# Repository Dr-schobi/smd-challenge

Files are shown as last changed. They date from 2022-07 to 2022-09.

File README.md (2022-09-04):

# SMD soldering challenge

https://user-images.githubusercontent.com/78444256/188329124-fbfda367-b1dc-41d7-a8d5-ee6e349dee65.mp4

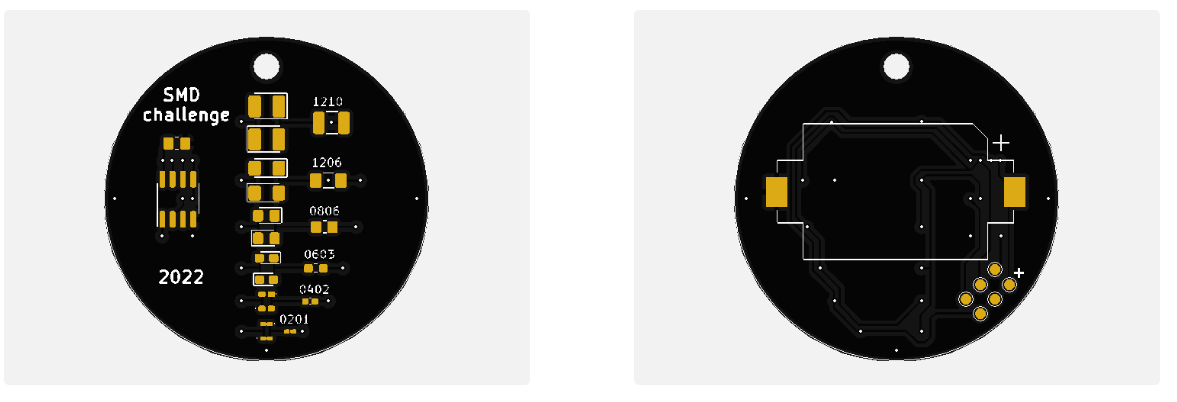
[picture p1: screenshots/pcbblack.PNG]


This project is about hand-soldering tiny SMD components onto a PCB. Similar to [Defcon](https://dchhv.org/events/smdsolderchallenge.html) in [2018](https://hackaday.com/2018/08/02/smd-soldering-challenge-lands-at-def-con/).

My goals:
- I wanna try! (both with and without extra tools).
  In the past, I've done some PCB development, debugging, soldering and measuring around 2008 for developing digital cameras, with large FPGAs (Xilinx Vertex), my own DDR memory controller on complex 10+ layer PCBs. Back then, this was no 0201 and I'm much older now with many years of just Matlab coding and only little electronics. 

- I don't think that I will succeed on the first try.
  I will need more than one shot with the tiny components, especially towards 0201. 
  the kit from the set above comes with one component each - this might not be enough.

- Learn some more! 
  The new Kicad 6 looks realy good and I'm lacking practice in PCB design, this looks like a good chance for a quick project with focus on aesthetics.   
  I've not worked wit Atmel microcontrollers for over 15 years - time to refresh.
  
- Maybe this is for sharing?
  In the last years, I met a few electronics developers who might like to be gifted a kit. I'm certainly not going to order just one set.

Status:
- PCBs have arrived, assembled and code is working

Errata: 
- silkscreen says "0806", should be "0805"

# Schematic and PCB

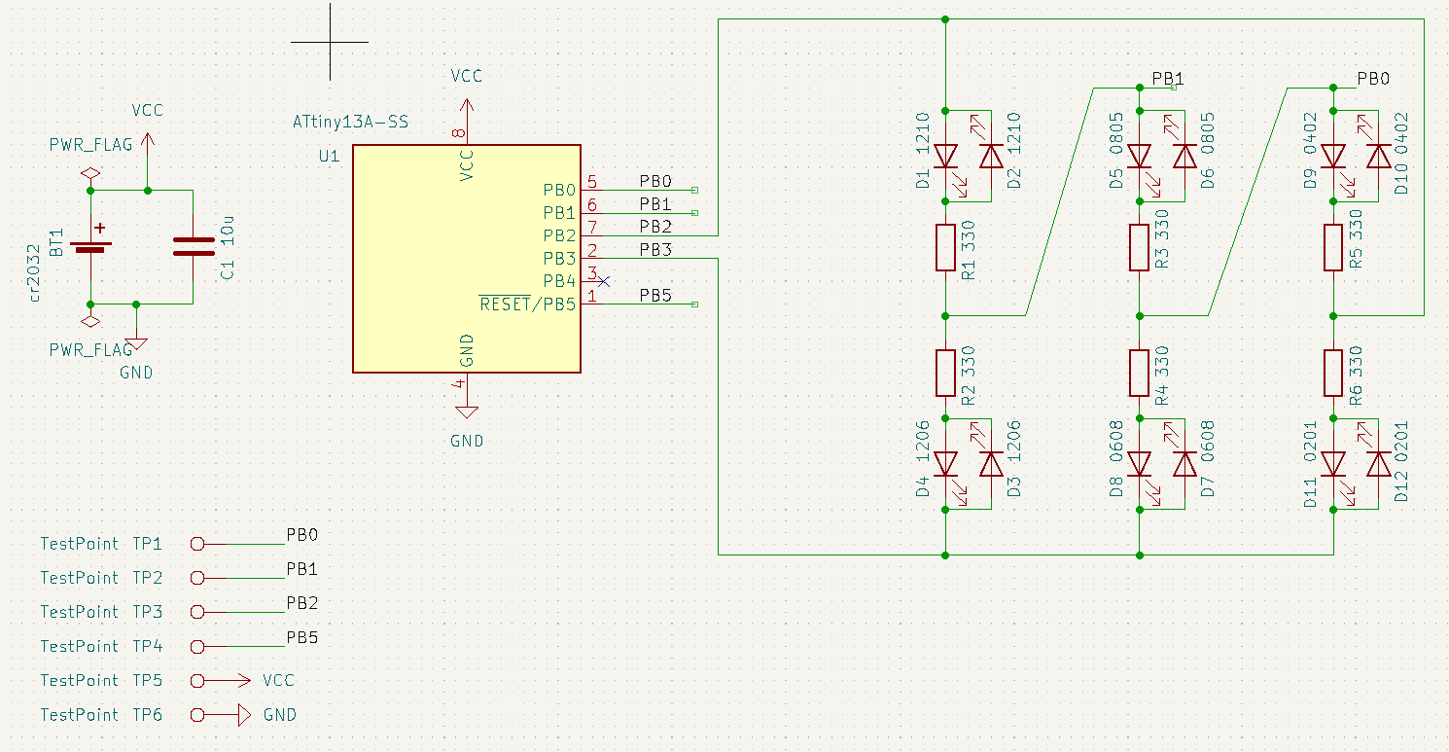
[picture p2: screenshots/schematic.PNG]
schematic


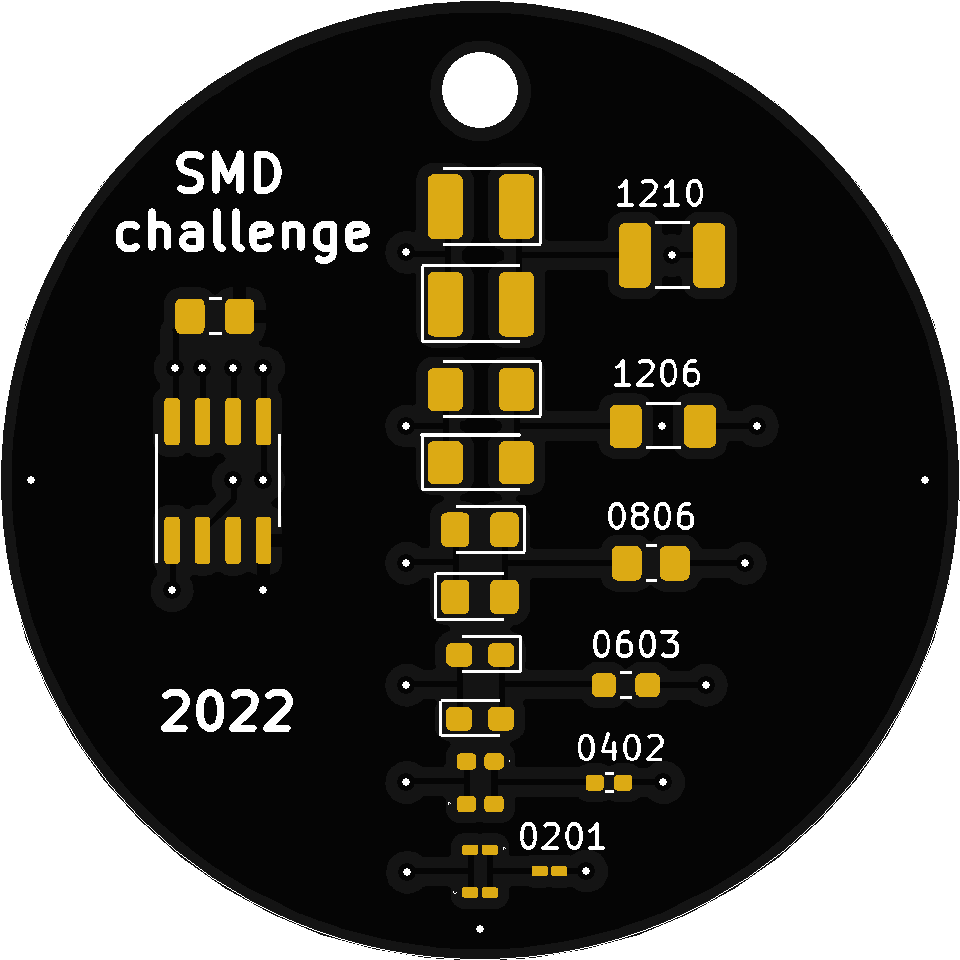
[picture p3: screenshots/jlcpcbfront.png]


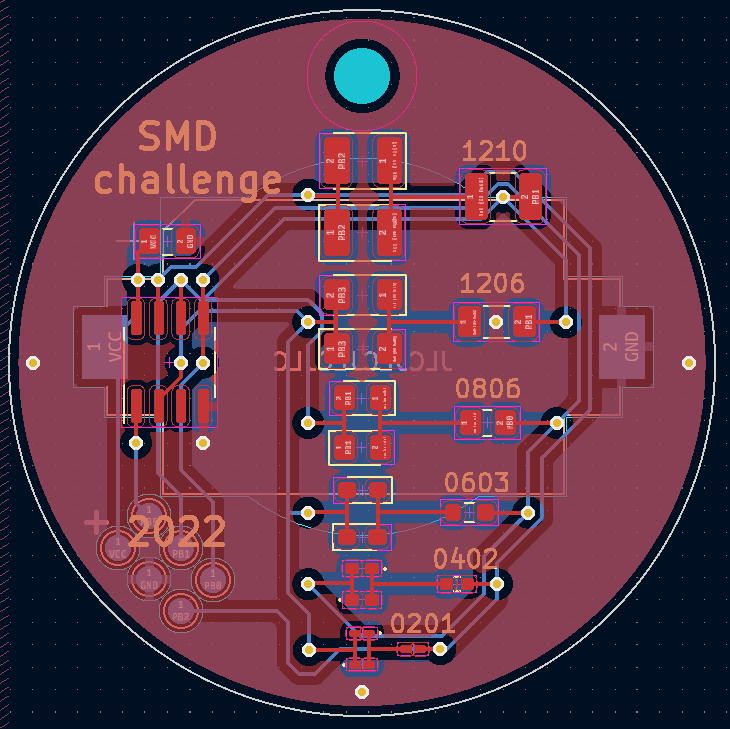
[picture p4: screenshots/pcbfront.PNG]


changes I made (on purpose)
- two LEDs per type, flip one other than the first, and everything will light up
- all LEDs in the center, I'm looking for an icicle christmas decoration effect of dropping light
- all LEDs wired to the controller, should be ably to drive one at a time, in any orientation

# Components

I put together a list of components I ordered from LCSC:

Resistors  (package, value, number of pieces I ordered, description):
- 0201 R 330Ohm    500  UNI-ROYAL(Uniroyal Elec) 0201WMF3300TEE   [LCSC Part # C516485](https://lcsc.com/product-detail/Chip-Resistor-Surface-Mount_UNI-ROYAL-Uniroyal-Elec-0201WMF3300TEE_C516485.html)
- 0201 R 330Ohm    500  Walsin Tech Corp WR02X3300FTL       [LCSC Part # C367585](https://lcsc.com/product-detail/Chip-Resistor-Surface-Mount_Walsin-Tech-Corp-WR02X3300FTL_C367585.html)
- 0402 R 330Ohm    300  FOJAN FRC0402F3300TS                [LCSC Part # C2930002](https://lcsc.com/product-detail/Chip-Resistor-Surface-Mount_FOJAN-FRC0402F3300TS_C2930002.html)
- 0603 R 330Ohm    300  FOJAN FRC0603F3300TS                [LCSC Part # C2933198](https://lcsc.com/product-detail/Chip-Resistor-Surface-Mount_FOJAN-FRC0603F3300TS_C2933198.html)
- 0803 R 330Ohm    300  FOJAN FRC0805F3300TS                [LCSC Part # C2930157](https://lcsc.com/product-detail/Chip-Resistor-Surface-Mount_FOJAN-FRC0805F3300TS_C2930157.html)
- 1206 R 330Ohm    300  FOJAN FRC1206F3300TS                [LCSC Part # C2933675](https://lcsc.com/product-detail/Chip-Resistor-Surface-Mount_FOJAN-FRC1206F3300TS_C2933675.html)
- 1210 R 330Ohm    150  FOJAN FRC1210F3300TS                [LCSC Part # C2933817](https://lcsc.com/product-detail/Chip-Resistor-Surface-Mount_FOJAN-FRC1210F3300TS_C2933817.html)

LEDs (package, value, number of pieces I ordered, description):
- 0201 LED red   150   XINGLIGHT XL-0201SURC        [LCSC Part # C3646923](https://lcsc.com/product-detail/Light-Emitting-Diodes-LED_XINGLIGHT-XL-0201SURC_C3646923.html)
- 0402 LED red   100   XINGLIGHT XL-1005SURC        [LCSC Part # C965790](https://lcsc.com/product-detail/Light-Emitting-Diodes-LED_XINGLIGHT-XL-1005SURC_C965790.html)
- 0603 LED red   100   XINGLIGHT XL-1608SURC-06     [LCSC Part # C965799](https://lcsc.com/product-detail/Light-Emitting-Diodes-LED_XINGLIGHT-XL-1608SURC-06_C965799.html)
- 0805 LED red   100   XINGLIGHT XL-2012SURC        [LCSC Part # C965812](https://lcsc.com/product-detail/Light-Emitting-Diodes-LED_XINGLIGHT-XL-2012SURC_C965812.html)
- 1206 LED red   100   TUOZHAN P2-1206RTCS2-0.9T-F  [LCSC Part # C2827254](https://lcsc.com/product-detail/Light-Emitting-Diodes-LED_TUOZHAN-P2-1206RTCS2-0-9T-F_C2827254.html)
- 1210 LED red   100   XINGLIGHT XL-3227SURUGC      [LCSC Part # C965842](https://lcsc.com/product-detail/Light-Emitting-Diodes-LED_XINGLIGHT-XL-3227SURUGC_C965842.html)

Others
- 0603 C 10uF10V  100    Samsung Electro-Mechanics CL10A106KP8NNNC  [LCSC Part # C19702](https://lcsc.com/product-detail/Multilayer-Ceramic-Capacitors-MLCC-SMD-SMT_Samsung-Electro-Mechanics-CL10A106KP8NNNC_C19702.html)
- SIOC-8 150mil  15x    Microchip Tech ATTINY13A-SSU   [LCSC Part # C14075](https://lcsc.com/product-detail/ATMEL-AVR_Microchip-Tech-ATTINY13A-SSU_C14075.html)
- Batt    15x   Q&J CR2032-BS-6-1   [LCSC Part # C70377](https://lcsc.com/product-detail/Battery-Connectors_Q-J-CR2032-BS-6-1_C70377.html)

# Results

I packed a few kits with a programmed Attiny13 already on the board. I'm waiting for assembly feedback.

IMG_20220904_204031101_cut

IMG_20220904_204101881_cut
IMG_20220904_204820867_cut

# Power consumption
measured with 3V supply and 12Ohm resistor
- 12x LED flash of 5msec, 42mV -> 3.5mA, energy of 17.5 mA msec
- 12x pause between flashes 375msec, <0.01mA, energy of 3.75 mA msec
- long pause 1.5sec, <0.01mA, energy of 15 mA msec

Total of 6060msec and energy of 270 mA msec, average current of 0.045mA
In theory, a CR2032 coin cell with 120mAh could last >100 days - let's see.

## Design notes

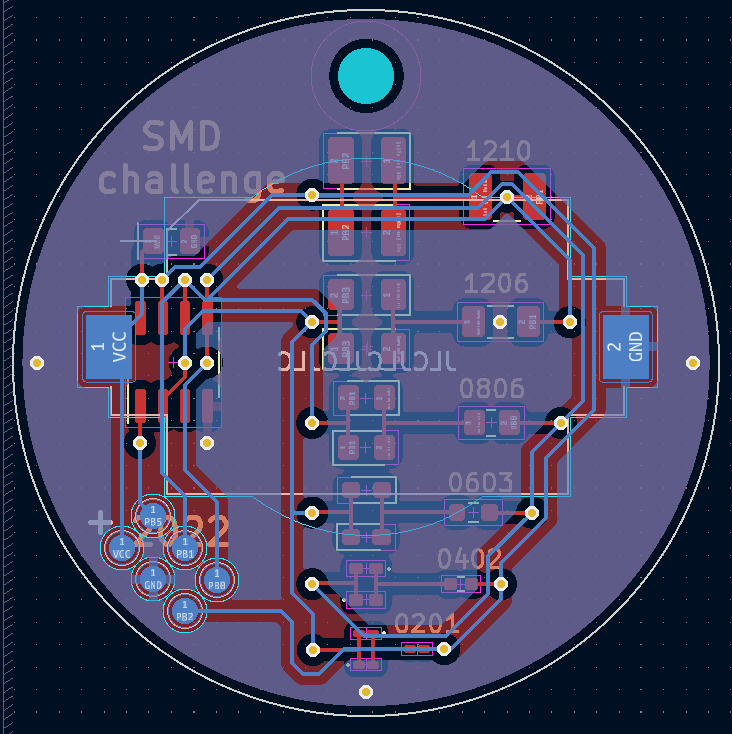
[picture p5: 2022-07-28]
screenshots/pcbback.PNG

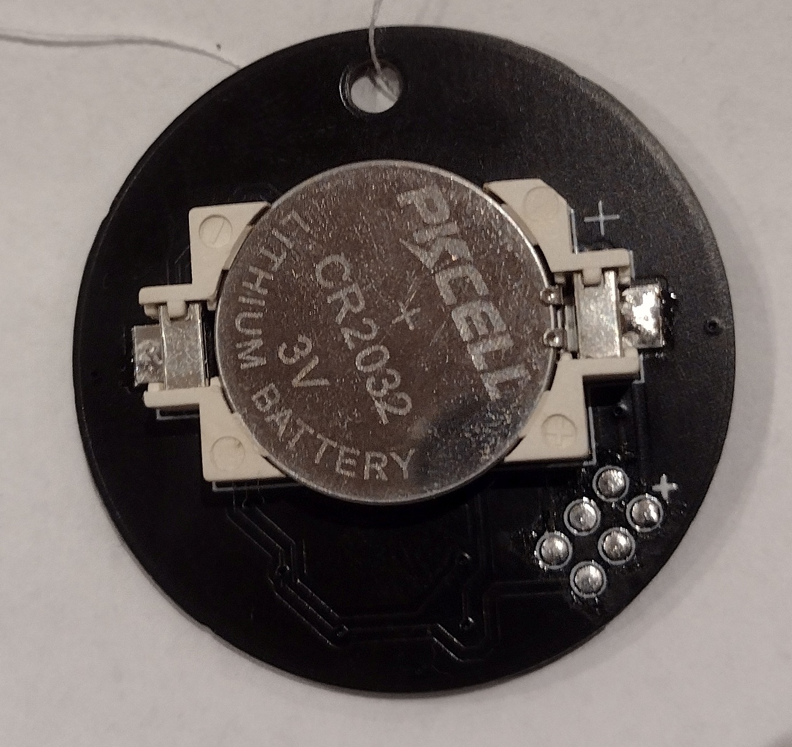
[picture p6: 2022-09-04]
screenshots/IMG_20220904_204031101_cut.jpg

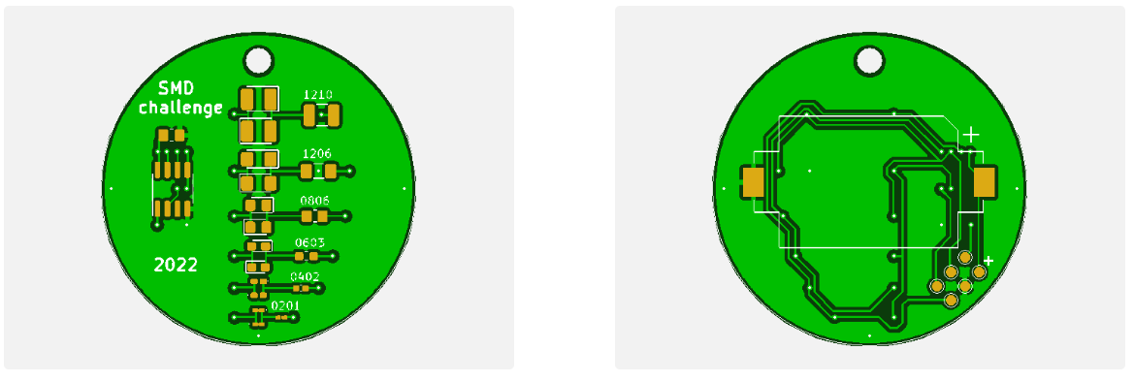
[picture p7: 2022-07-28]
screenshots/pcbgreen.PNG

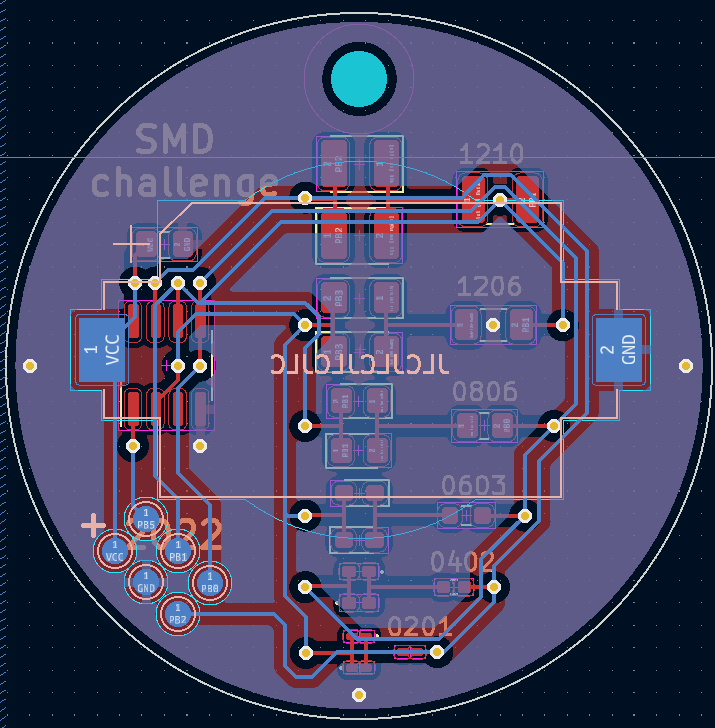
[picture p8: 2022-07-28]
screenshots/pcb.PNG

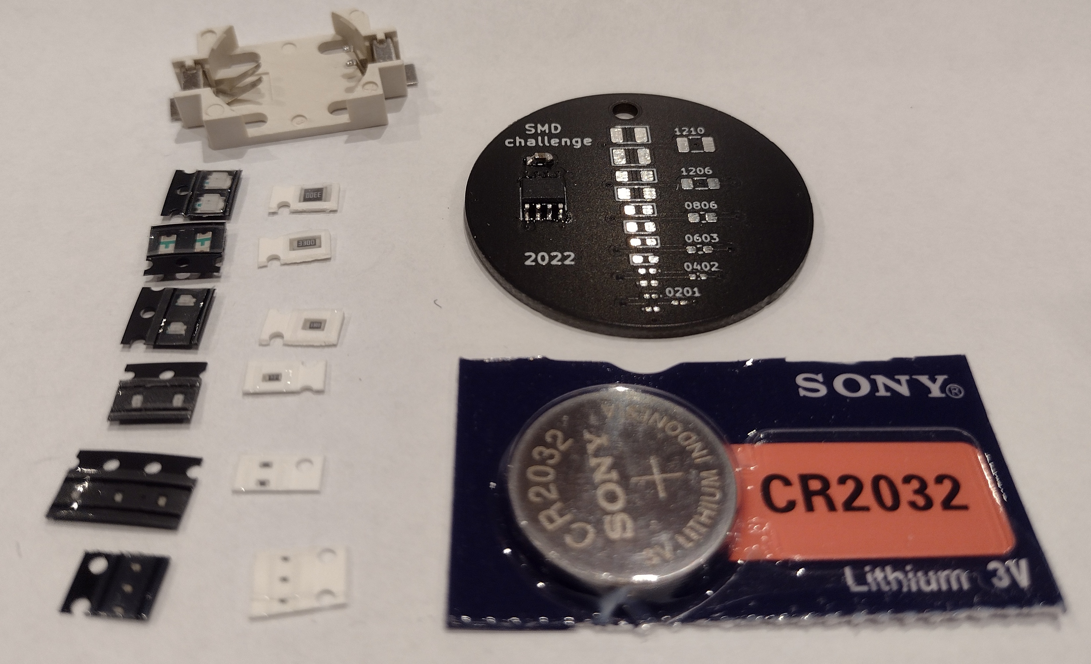
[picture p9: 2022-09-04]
screenshots/IMG_20220904_204820867_cut.jpg

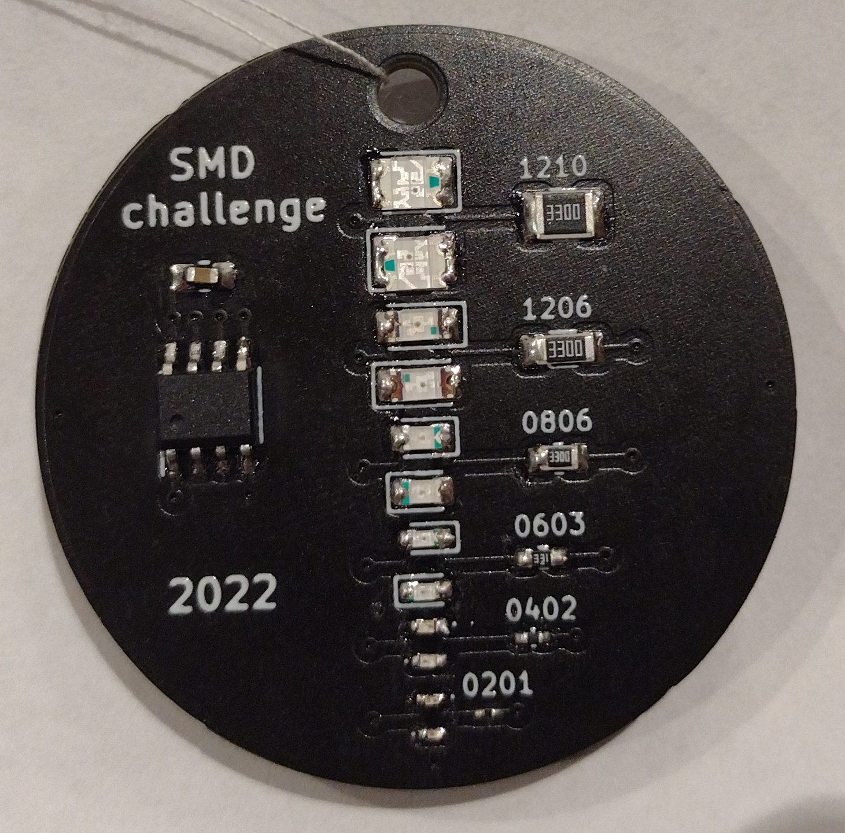
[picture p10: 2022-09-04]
screenshots/IMG_20220904_204101881_cut.jpg

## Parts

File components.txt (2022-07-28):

0201 R 330Ohm    500  UNI-ROYAL(Uniroyal Elec) 0201WMF3300TEE   LCSC Part # C516485
0201 R 330Ohm    500  Walsin Tech Corp WR02X3300FTL       LCSC Part # C367585  
0402 R 330Ohm    300  FOJAN FRC0402F3300TS                LCSC Part # C2930002
0603 R 330Ohm    300  FOJAN FRC0603F3300TS                LCSC Part # C2933198
0803 R 330Ohm    300  FOJAN FRC0805F3300TS                LCSC Part # C2930157
1206 R 330Ohm    300  FOJAN FRC1206F3300TS                LCSC Part # C2933675
1210 R 330Ohm    150  FOJAN FRC1210F3300TS                LCSC Part # C2933817

0201 LED red   150   XINGLIGHT XL-0201SURC        LCSC Part # C3646923
0402 LED red   100   XINGLIGHT XL-1005SURC        LCSC Part # C965790
0603 LED red   100   XINGLIGHT XL-1608SURC-06     LCSC Part # C965799 
0805 LED red   100   XINGLIGHT XL-2012SURC        LCSC Part # C965812
1206 LED red   100   TUOZHAN P2-1206RTCS2-0.9T-F  LCSC Part # C2827254
1210 LED red   100   XINGLIGHT XL-3227SURUGC      LCSC Part # C965842

0603 C 10uF10V  100    Samsung Electro-Mechanics CL10A106KP8NNNC  LCSC Part # C19702

SIOC-8 150mil  15x    Microchip Tech ATTINY13A-SSU   LCSC Part # C14075
Batt    15x   Q&J CR2032-BS-6-1   LCSC Part # C70377

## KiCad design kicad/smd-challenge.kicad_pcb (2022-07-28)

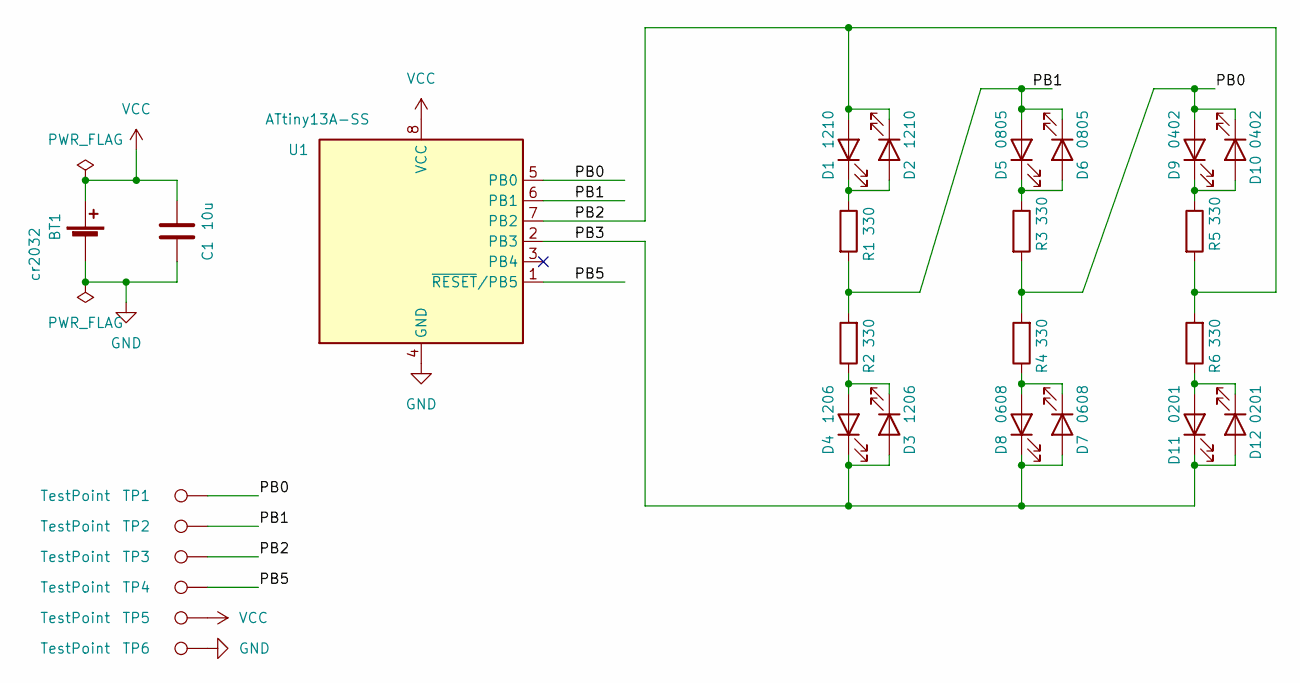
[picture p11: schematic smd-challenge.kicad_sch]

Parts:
BT1: cr2032; BatteryHolder_Keystone_1060_1x2032
C1: 10u; C_0805_2012Metric_Pad1.18x1.45mm_HandSolder
D1, D2: 1210; LED_1210_3225Metric_Pad1.42x2.65mm_HandSolder
D3, D4: 1206; LED_1206_3216Metric_Pad1.42x1.75mm_HandSolder
D5, D6: 0805; LED_0805_2012Metric_Pad1.15x1.40mm_HandSolder
D7, D8: 0608; LED_0603_1608Metric_Pad1.05x0.95mm_HandSolder
D9, D10: 0402; LED_0402_1005Metric_Pad0.77x0.64mm_HandSolder
D11, D12: 0201; LED_0201_0603Metric_Pad0.64x0.40mm_HandSolder
R1: 330; R_1210_3225Metric_Pad1.30x2.65mm_HandSolder
R2: 330; R_1206_3216Metric_Pad1.30x1.75mm_HandSolder
R3: 330; R_0805_2012Metric_Pad1.20x1.40mm_HandSolder
R4: 330; R_0603_1608Metric_Pad0.98x0.95mm_HandSolder
R5: 330; R_0402_1005Metric_Pad0.72x0.64mm_HandSolder
R6: 330; R_0201_0603Metric_Pad0.64x0.40mm_HandSolder
TP1, TP2, TP3, TP4, TP5, TP6: TestPoint; TestPoint_Pad_D1.5mm
U1: ATtiny13A-SS; SOIC-8_3.9x4.9mm_P1.27mm; LCSC C14075

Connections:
/PB0: D9.2 (A), D10.1 (K), R3.2, R4.2, TP1.1, U1.5 (PB0)
/PB1: D5.2 (A), D6.1 (K), R1.2, R2.2, TP2.1, U1.6 (PB1)
/PB2: D1.2 (A), D2.1 (K), R5.2, R6.2, TP3.1, U1.7 (PB2)
/PB3: D3.2 (A), D4.1 (K), D7.2 (A), D8.1 (K), D11.1 (K), D12.2 (A), U1.2 (PB3)
/PB5: TP4.1, U1.1 (~RESET/PB5)
GND: BT1.2 (-), C1.2, TP6.1, U1.4 (GND)
unnamed: D1.1 (K), D2.2 (A), R1.1
unnamed: D3.1 (K), D4.2 (A), R2.1
unnamed: D5.1 (K), D6.2 (A), R3.1
unnamed: D7.1 (K), D8.2 (A), R4.1
unnamed: D9.1 (K), D10.2 (A), R5.1
unnamed: D11.2 (A), D12.1 (K), R6.1
VCC: BT1.1 (+), C1.1, TP5.1, U1.8 (VCC)

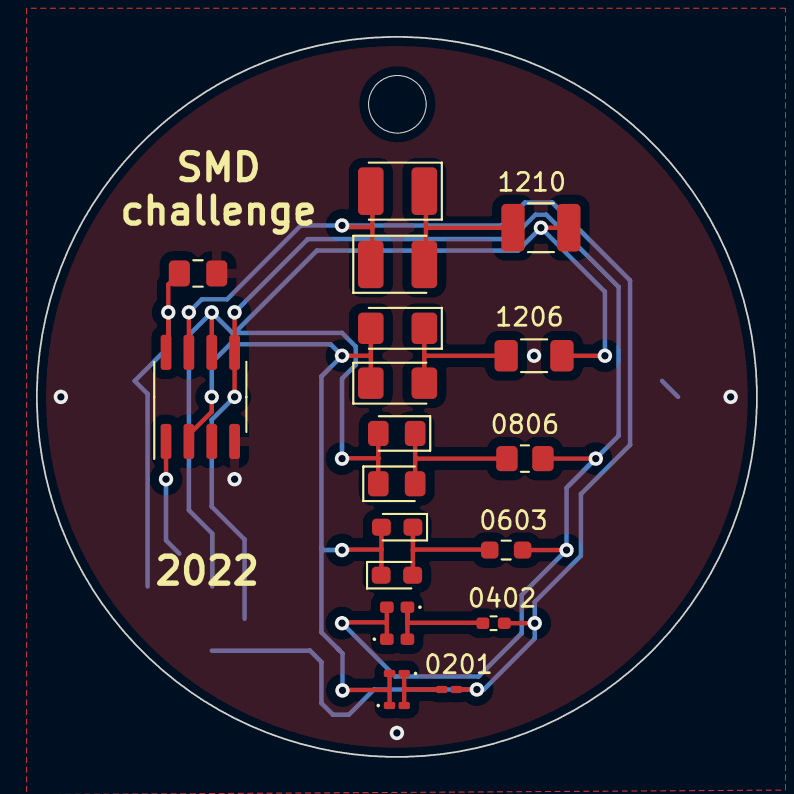
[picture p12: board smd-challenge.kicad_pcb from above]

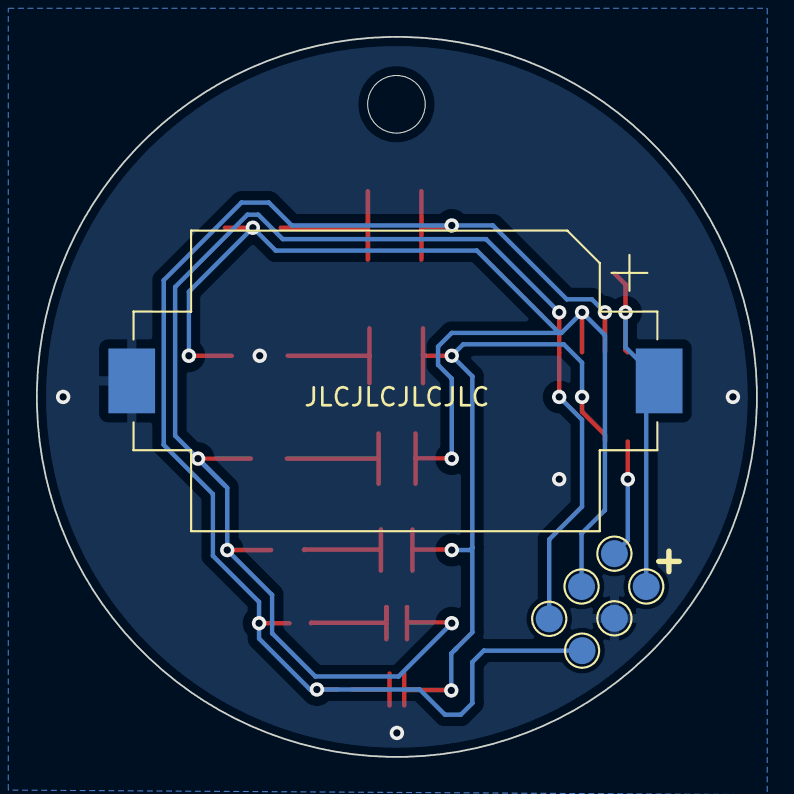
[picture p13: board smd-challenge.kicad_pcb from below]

Board: 2 copper layers, 40.0 x 40.0 mm, 27 parts (7 on the bottom side), 13 nets.

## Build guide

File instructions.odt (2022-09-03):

SMD challenge instructions

solder the missing SMD components
(LEDs, R) fully assembled, the LEDs
will blink in sequence

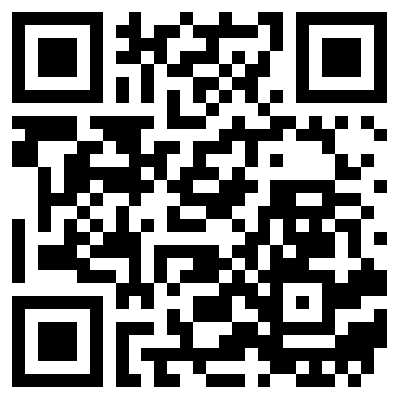
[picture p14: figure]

two LEDs per size,
alternating polarity,
start with green
marking on the right

LEDs

R

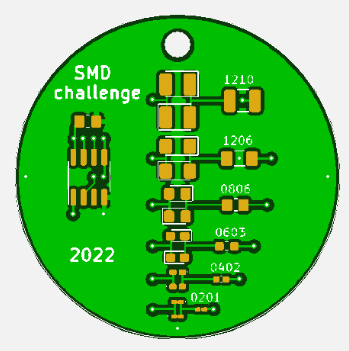
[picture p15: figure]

https://github.com/Dr-schobi/smd-challenge/

Version 2022-09

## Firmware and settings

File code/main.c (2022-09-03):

#include <avr/io.h>
#include <util/delay.h>
#include <avr/sleep.h>
#include <avr/wdt.h>
#include <avr/interrupt.h>

void blink(int A, int B) {

    // enable LED from A to B
    DDRB = ( 1 << A ) | ( 1 << B );
    PORTB |= ( 1 << A ); 
    PORTB &= ~( 1 << B );
    _delay_ms(5);
    DDRB = 0;
    
    WDTCR = _BV(WDTIE) |  _BV(WDP1) | _BV(WDP0);    // enable WDT Interrupt, Set WDT 125MS
    wdt_reset();
    sei();
    sleep_mode();
    cli();
    
    WDTCR = _BV(WDTIE) |  _BV(WDP2);    // enable WDT Interrupt, Set WDT 250MS
    wdt_reset();
    sei();
    sleep_mode();
    cli();

}

ISR(WDT_vect) { 

}



int main( void ) {
    
    set_sleep_mode(SLEEP_MODE_PWR_DOWN);
 
    while( 1 ) {       
             
        blink( PB2, PB1 );
        blink( PB1, PB2 );

        blink( PB3, PB1 );
        blink( PB1, PB3 );
        
        blink( PB1, PB0 );
        blink( PB0, PB1 );

        blink( PB3, PB0 );
        blink( PB0, PB3 );
        
        blink( PB0, PB2 );
        blink( PB2, PB0 );
        
        blink( PB3, PB2 );
        blink( PB2, PB3 );


        WDTCR = _BV(WDTIE) |  _BV(WDP2) | _BV(WDP1);    // enable WDT Interrupt, Set WDT 1S    
        wdt_reset();
        sei();
        sleep_mode();
        cli();

        WDTCR = _BV(WDTIE) |  _BV(WDP2) | _BV(WDP0);    // enable WDT Interrupt, Set WDT 500MS
        wdt_reset();
        sei();
        sleep_mode();
        cli();
  
    }
 
    return 0;
}

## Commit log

2022-07-28 added files and descriptions
    [smd-challenge-B_Cu.gbl, smd-challenge-B_Mask.gbs, smd-challenge-B_Paste.gbp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]
2022-09-03 added code for LED blinking and smd assembly instructions
    [power consumption.ods]
2022-09-04 updated documentation and results photos
    [power consumption.ods]
